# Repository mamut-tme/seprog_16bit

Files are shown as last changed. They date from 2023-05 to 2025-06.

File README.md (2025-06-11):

# seprog_16bit
16bit chip adapter for the WG Electronics Seprog programmer

## Info in english:
This repo describes a 16-bit chip adapter for the eprom programmer "Seprog" from the polish manufacturer WG Electronics. The rest will be in polish, because I don't belive that anyone outside of Poland will be interested in this information.

To repozytorium zawiera schemat i płytkę zaprojektowaną w oprogramowaniu Kicad do adaptera do 16-bitowych układów EPROM (tych kasowalnych UV) do programatora Seprog firmy WG Electronics. Schemat opracowałem przez analizę działania mojego programatora z firmware w wersji 1.49 (bardzo możliwe, że niższe wersje oprogramowania nie wspierają tych układów, 1.00 nie wspiera - sprawdzono).

Obsługiwane układy (natywnie, przez programator i oryginalne oprogramowanie), podstawka DIL40:
- 27C1024
- 27C2048
- 27C4096

Mój adapter umożliwia ponadto programowanie, podstawka DIL42:
- 27C160
- 27C322
- 27C400
- 27C800

przez ręczne przełączanie banków pamięci (pomysł z https://github.com/mafe72/27c160-tl866-adapter) używając w oprogramowaniu trybu 27C4096)

## Schemat adaptera:
Schemat

## Problemy:
- Używając algorytmu INTELIgent programator zasila układ programowany (więc również nasz adapter) napięciem 6,25V (zgodnie z dokumentacją np. AM27C160), co już jest poza specyfikacją układów z serii 74HC. U mnie nawet na HCT działało dobrze i po wielu zapisach układy nie uległy uszkodzeniu, ale trzeba to mieć na uwadze.
- Aplikacja wSeprog napisana przez użytkownika jurex portalu elektroda.pl (https://www.elektroda.pl/rtvforum/topic857189.html) niestety niezupełnie poprawnie obsługuje układy 16 bitowe (konieczna jest zamiana sygnałów Q4 i Q6, tak robi oryginalne oprogramowanie pod DOSa, więc zakładam, że oryginalny adapter też tak miał)
- Wzór płytki nie został póki co sprawdzony w praktyce (mam wykonany prototyp z bankowaniem dla większych układów, ale nie przemyślałem aspektu dźwigienki podstawki ZIF programatora i potrzebne są długie goldpiny, adapter bardzo niestabilnie "siedzi").
- Programowanie jest bardzo powolne - ok. 15 minut na jeden bank "27C4096" i to jest czas dla najszybszego algorytmu INTELIgent

## Jeszcze kilka porad dla startujących z tym programatorem:
- Oryginalna aplikacja pod dosa chodzi bardzo dobrze z emulatorem DOSbox (https://www.dosbox.com/), trzeba tylko przekierować port COM emulatora do rzeczywistego portu komputera (może być adapter na USB, programator używa tylko linii RXD i TXD)
- Przypadki związane z losowymi błędami odczytu i zapisu mogą być spowodowane kiepskim zasilaniem. Powinien wystarczyć zasilacz niestabilizowany, oryginalnie chyba był 9V 500mA. Programator ma własny stabilizator 5V i przetwornicę impulsową (nie zapominajmy, że on obsługuje też bardzo stare EPROMy 21V!)

## Render 3D płytki
dla ciekawych

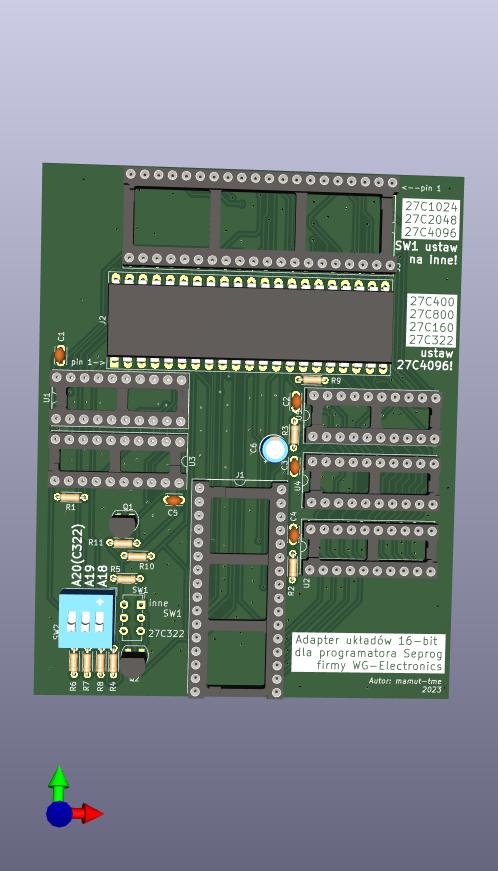
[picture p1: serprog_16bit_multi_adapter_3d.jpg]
Płytka3D


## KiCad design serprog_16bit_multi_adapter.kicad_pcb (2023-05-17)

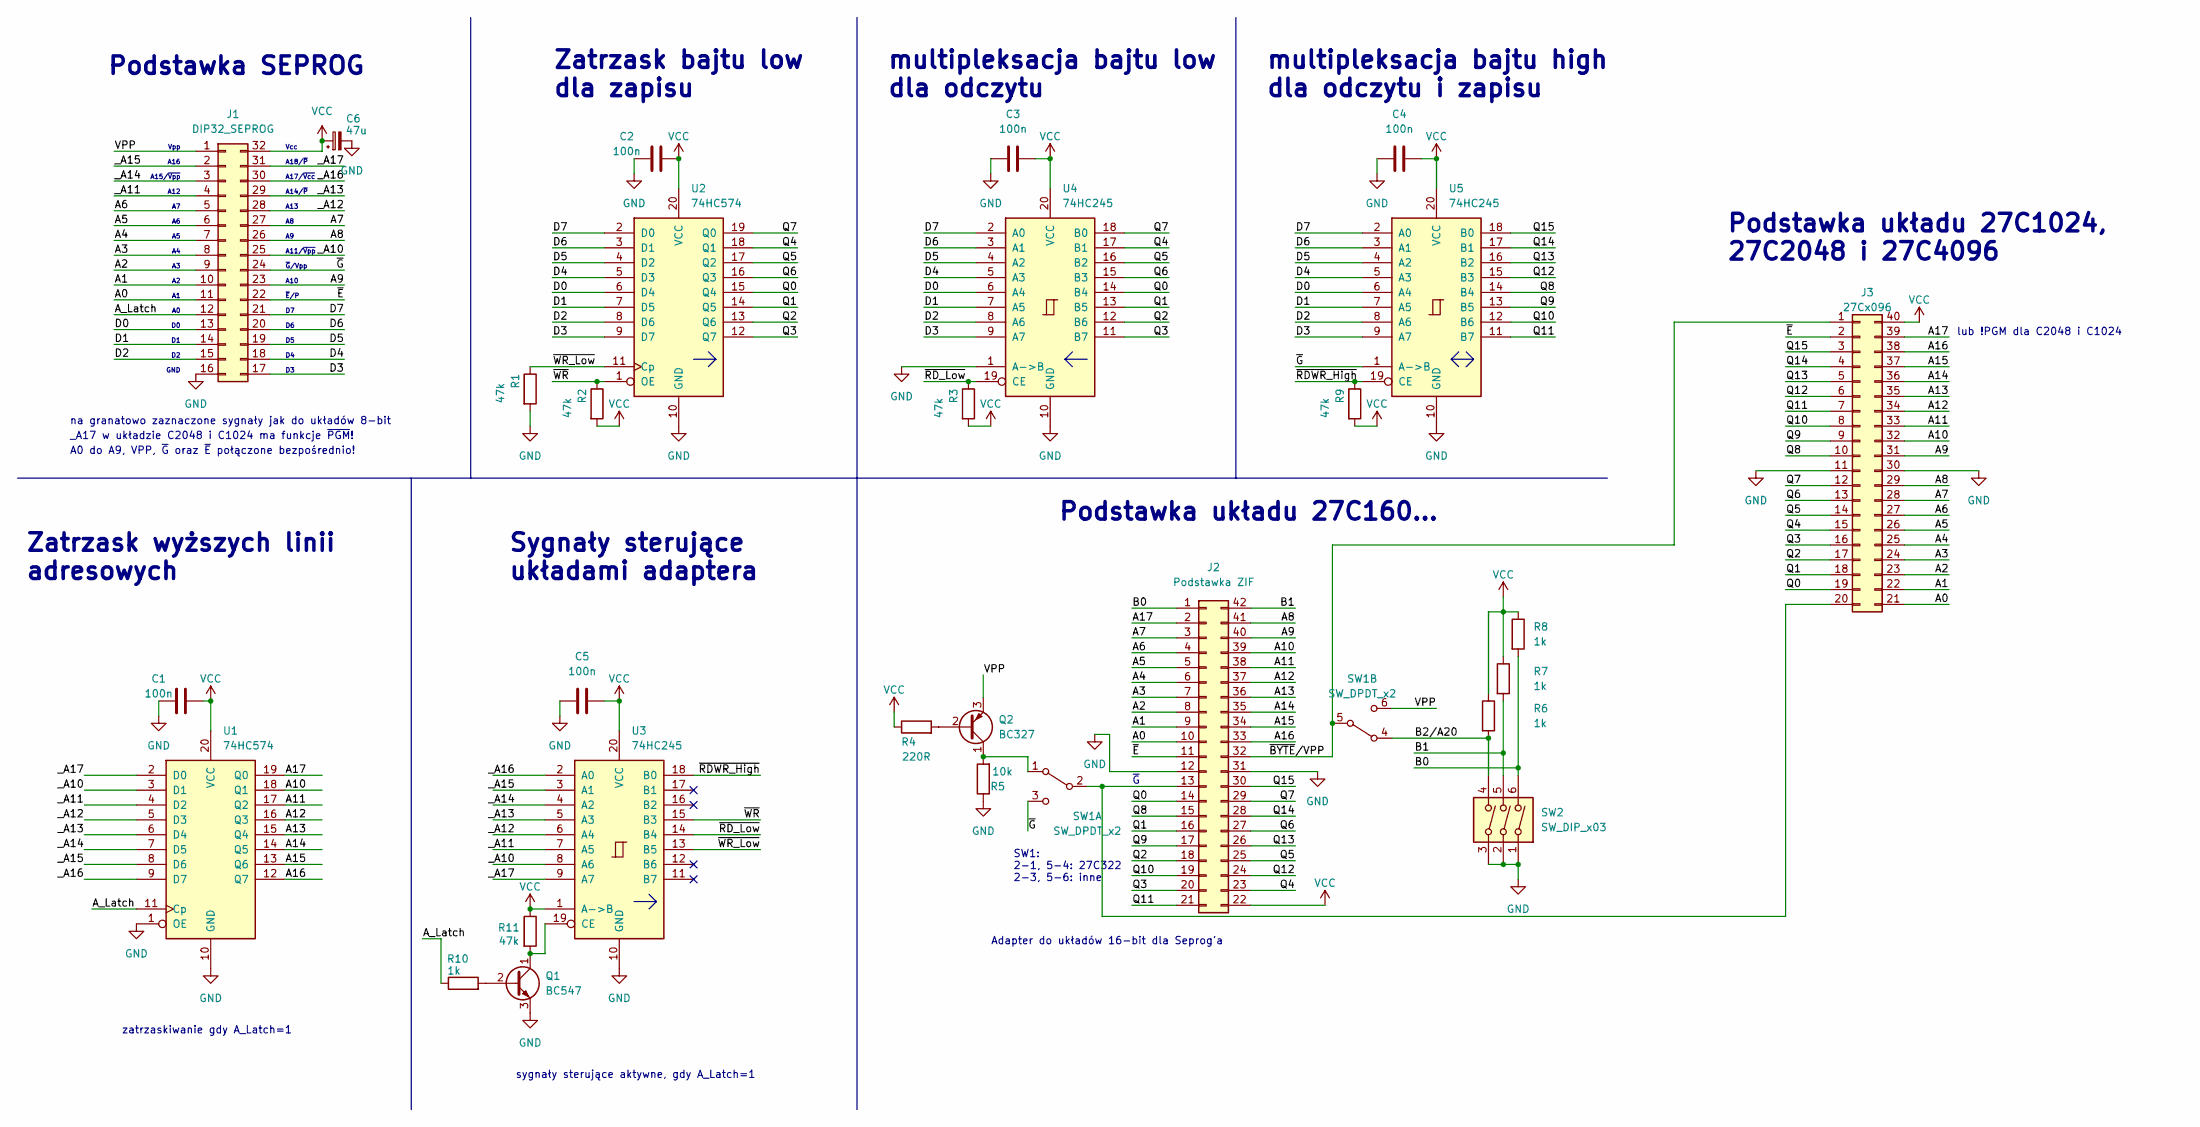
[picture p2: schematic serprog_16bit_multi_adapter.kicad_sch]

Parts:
C1, C2, C3, C4, C5: 100n; C_Disc_D3.0mm_W2.0mm_P2.50mm
C6: 47u; CP_Radial_D5.0mm_P2.50mm
J1: DIP32_SEPROG; DIP-32_W15.24mm_Socket_LongPads
J2: Podstawka ZIF; DIP-42_W15.24mm_Socket_LongPads
J3: 27Cx096; DIP-40_W15.24mm_Socket_LongPads
Q1: BC547; TO-92_HandSolder
Q2: BC327; TO-92_HandSolder
R1, R2, R3, R9, R11: 47k; R_Axial_DIN0204_L3.6mm_D1.6mm_P5.08mm_Horizontal
R4: 220R; R_Axial_DIN0204_L3.6mm_D1.6mm_P5.08mm_Horizontal
R5: 10k; R_Axial_DIN0204_L3.6mm_D1.6mm_P5.08mm_Horizontal
R6, R7, R8, R10: 1k; R_Axial_DIN0204_L3.6mm_D1.6mm_P5.08mm_Horizontal
SW1: SW_DPDT_x2; SW_E-Switch_EG1271_SPDT
SW2: SW_DIP_x03; SW_DIP_SPSTx03_Slide_9.78x9.8mm_W7.62mm_P2.54mm
U1, U2: 74HC574; DIP-20_W7.62mm_Socket_LongPads
U3, U4, U5: 74HC245; DIP-20_W7.62mm_Socket_LongPads

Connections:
/A0: J1.11, J2.10, J3.21
/A1: J1.10, J2.9, J3.22
/A2: J1.9, J2.8, J3.23
/A3: J1.8, J2.7, J3.24
/A4: J1.7, J2.6, J3.25
/A5: J1.6, J2.5, J3.26
/A6: J1.5, J2.4, J3.27
/A7: J1.27, J2.3, J3.28
/A8: J1.26, J2.41, J3.29
/A9: J1.23, J2.40, J3.31
/A10: J2.39, J3.32, U1.18 (Q1)
/A11: J2.38, J3.33, U1.17 (Q2)
/A12: J2.37, J3.34, U1.16 (Q3)
/A13: J2.36, J3.35, U1.15 (Q4)
/A14: J2.35, J3.36, U1.14 (Q5)
/A15: J2.34, J3.37, U1.13 (Q6)
/A16: J2.33, J3.38, U1.12 (Q7)
/A17: J2.2, J3.39, U1.19 (Q0)
/A_Latch: J1.12, R10.1, U1.11 (Cp)
/B0: J2.1, R8.2, SW2.6
/B1: J2.42, R7.2, SW2.5
/B2/A20: R6.2, SW1.4 (A), SW2.4
/D0: J1.13, U2.6 (D4), U4.6 (A4), U5.6 (A4)
/D1: J1.14, U2.7 (D5), U4.7 (A5), U5.7 (A5)
/D2: J1.15, U2.8 (D6), U4.8 (A6), U5.8 (A6)
/D3: J1.17, U2.9 (D7), U4.9 (A7), U5.9 (A7)
/D4: J1.18, U2.5 (D3), U4.5 (A3), U5.5 (A3)
/D5: J1.19, U2.4 (D2), U4.4 (A2), U5.4 (A2)
/D6: J1.20, U2.3 (D1), U4.3 (A1), U5.3 (A1)
/D7: J1.21, U2.2 (D0), U4.2 (A0), U5.2 (A0)
/Q0: J2.14, J3.19, U2.15 (Q4), U4.14 (B4)
/Q1: J2.16, J3.18, U2.14 (Q5), U4.13 (B5)
/Q2: J2.18, J3.17, U2.13 (Q6), U4.12 (B6)
/Q3: J2.20, J3.16, U2.12 (Q7), U4.11 (B7)
/Q4: J2.23, J3.15, U2.18 (Q1), U4.17 (B1)
/Q5: J2.25, J3.14, U2.17 (Q2), U4.16 (B2)
/Q6: J2.27, J3.13, U2.16 (Q3), U4.15 (B3)
/Q7: J2.29, J3.12, U2.19 (Q0), U4.18 (B0)
/Q8: J2.15, J3.10, U5.14 (B4)
/Q9: J2.17, J3.9, U5.13 (B5)
/Q10: J2.19, J3.8, U5.12 (B6)
/Q11: J2.21, J3.7, U5.11 (B7)
/Q12: J2.24, J3.6, U5.15 (B3)
/Q13: J2.26, J3.5, U5.16 (B2)
/Q14: J2.28, J3.4, U5.17 (B1)
/Q15: J2.30, J3.3, U5.18 (B0)
/VPP: J1.1, Q2.3 (E), SW1.6 (C)
/_A10: J1.25, U1.3 (D1), U3.8 (A6)
/_A11: J1.4, U1.4 (D2), U3.7 (A5)
/_A12: J1.28, U1.5 (D3), U3.6 (A4)
/_A13: J1.29, U1.6 (D4), U3.5 (A3)
/_A14: J1.3, U1.7 (D5), U3.4 (A2)
/_A15: J1.2, U1.8 (D6), U3.3 (A1)
/_A16: J1.30, U1.9 (D7), U3.2 (A0)
/_A17: J1.31, U1.2 (D0), U3.9 (A7)
/~BYTE/VPP: J2.32, J3.1, SW1.5 (B)
/~E: J1.22, J2.11, J3.2
/~G: J1.24, SW1.3 (C), U5.1 (A->B)
/~RDWR_High: R9.1, U3.18 (B0), U5.19 (CE)
/~RD_Low: R3.1, U3.14 (B4), U4.19 (CE)
/~WR_Low: R1.1, U2.11 (Cp), U3.13 (B5)
/~WR: R2.1, U2.1 (OE), U3.15 (B3)
GND: C1.2, C2.2, C3.2, C4.1, C5.1, C6.2, J1.16, J2.12, J2.31, J3.11, J3.30, Q1.3 (E), R1.2, R5.1, SW2.1, SW2.2, SW2.3, U1.1 (OE), U1.10 (GND), U2.10 (GND), U3.10 (GND), U4.1 (A->B), U4.10 (GND), U5.10 (GND)
unnamed: J2.13, J3.20, SW1.2 (B)
unnamed: Q1.2 (B), R10.2
unnamed: Q1.1 (C), R11.2, U3.19 (CE)
unnamed: Q2.2 (B), R4.2
unnamed: Q2.1 (C), R5.2, SW1.1 (A)
VCC: C1.1, C2.1, C3.1, C4.2, C5.2, C6.1, J1.32, J2.22, J3.40, R2.2, R3.2, R4.1, R6.1, R7.1, R8.1, R9.2, R11.1, U1.20 (VCC), U2.20 (VCC), U3.1 (A->B), U3.20 (VCC), U4.20 (VCC), U5.20 (VCC)

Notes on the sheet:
Vpp A16 A15/~{Vpp} A12 A7 A6 A5 A4 A3 A2 A1 A0 D0 D1 D2 GND
zatrzaskiwanie gdy A_Latch=1
multipleksacja bajtu high dla odczytu i zapisu
Zatrzask wyższych linii adresowych
_A17 w układzie C2048 i C1024 ma funkcje ~{PGM}!
Sygnały sterujące układami adaptera
Podstawka układu 27C160...
Adapter do układów 16-bit dla Seprog'a
Vcc A18/~{P} A17/~{Vcc} A14/~{P} A13 A8 A9 A11/~{Vpp} ~{G}/Vpp A10 ~{E}/P D7 D6 D5 D4 D3
SW1: 2-1, 5-4: 27C322 2-3, 5-6: inne
A0 do A9, VPP, ~{G} oraz ~{E} połączone bezpośrednio!
~{G}
Zatrzask bajtu low dla zapisu
multipleksacja bajtu low dla odczytu
Podstawka układu 27C1024, 27C2048 i 27C4096
sygnały sterujące aktywne, gdy A_Latch=1
lub !PGM dla C2048 i C1024
Podstawka SEPROG
na granatowo zaznaczone sygnały jak do układów 8-bit

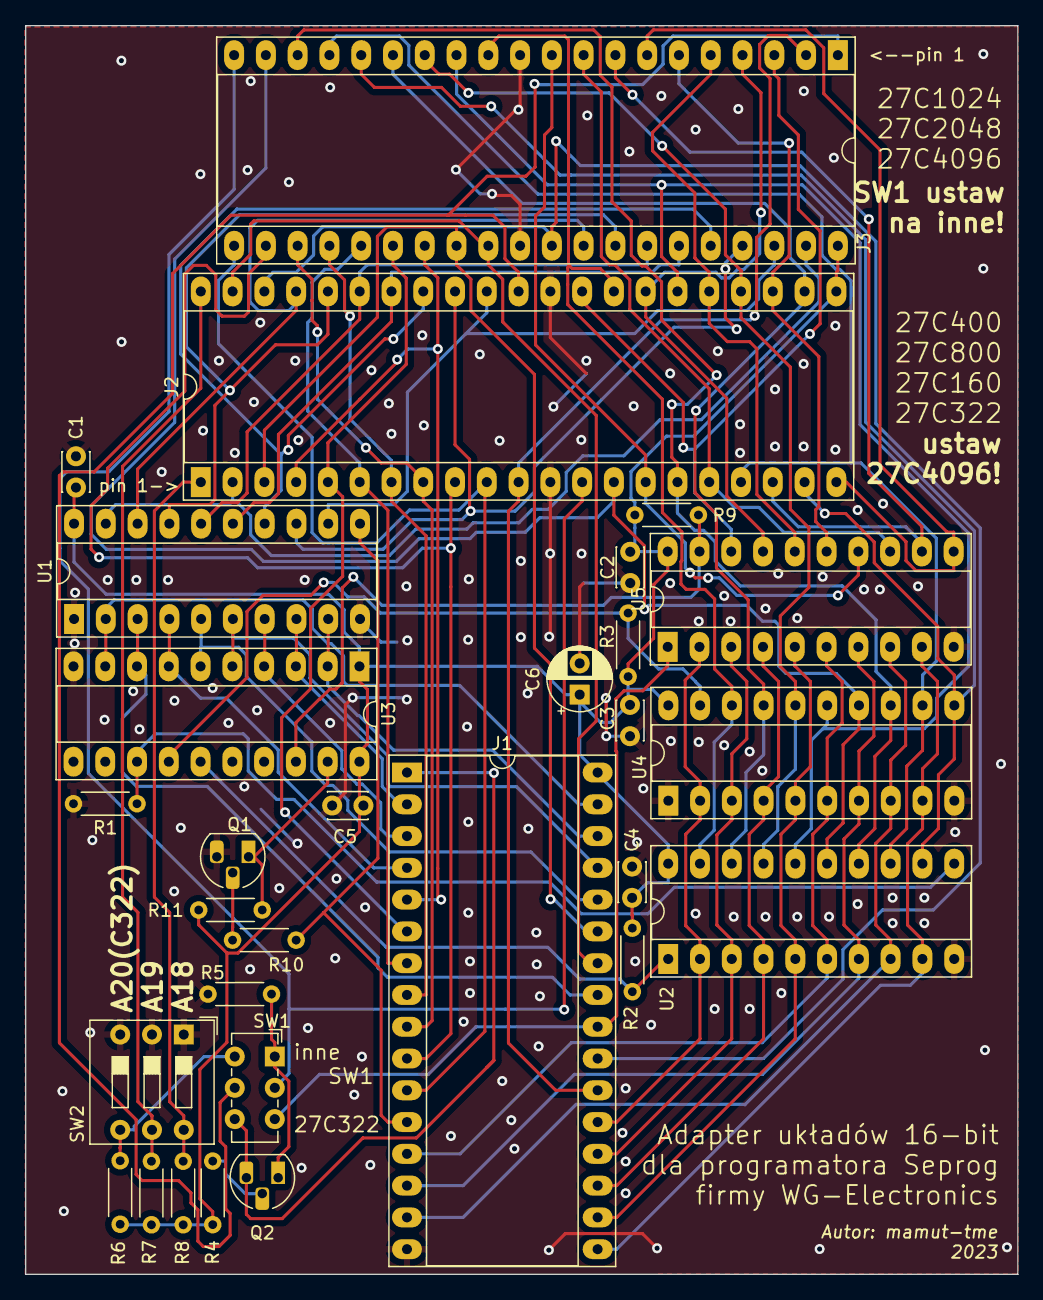
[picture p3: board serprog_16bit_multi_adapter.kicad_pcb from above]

Board: 2 copper layers, 79.3 x 99.8 mm, 29 parts (0 on the bottom side), 69 nets.
